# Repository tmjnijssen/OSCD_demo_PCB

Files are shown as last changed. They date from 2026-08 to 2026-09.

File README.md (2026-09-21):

# OSCD Demo PCB


A demonstration / teaching PCB built by the [Open Science Community Delft](https://www.tudelft.nl/en/library/open-science-community-delft) to show what an open hardware project looks like in practice: full sources, an open licence, and everything needed to have the board made and reprogrammed by anyone.

It is a round, ~93 mm ESP32-C3 board shaped like the OSCD logo, with a ring of 12 addressable RGB LEDs, three sensors on a shared I²C bus, capacitive touch pads, and three push buttons. Plug it into USB-C, and the demo firmware lights the ring in response to tilt, touch, ambient light, and button presses.

| | |
|---|---|
| **Revision** | 1.0 |
| **Designer** | Dr. ir. Tim M. J. Nijssen, Open Science Community Delft |
| **Licence** | [CERN-OHL-P v2](LICENSE) (permissive) |
| **EDA tool** | KiCad (2026-era release — see [Opening the design](#opening-the-design)) |

---

## Features

| Block | Part | Interface |
|---|---|---|
| Microcontroller | ESP32-C3-MINI-1 (RISC-V, Wi-Fi + BLE, native USB) | — |
| RGB LEDs | 12 × WS2812B-2020, in a 63 mm ring | 1-wire, `GPIO8` |
| IMU | LSM6DS3 — 3-axis accelerometer + gyroscope | I²C `0x6A` |
| Ambient light | APDS-9306-065 | I²C `0x52` |
| Capacitive touch | MPR121 — 12 electrodes (6 buttons + 6-pad slider) | I²C `0x5A`, IRQ on `GPIO10` |
| Buttons | 3 × user push button, plus RESET and BOOT | `GPIO0/1/2` |
| Power | USB-C 5 V → HT7533-1 LDO → 3.3 V | — |
| Breakout | 2 × 2×5 pin header (5 V, 3.3 V, GND, 9 GPIO) | 2.54 mm |
| Test points | 5 V, 3.3 V, SDA, SCL (each via 100 Ω) | — |

There is no USB-UART bridge — the ESP32-C3's native USB peripheral is wired straight to the USB-C connector, protected by a USBLC6-2SC6 ESD array.

## Quick start

1. **Power it.** Connect a USB-C cable to `J1`. The board is bus-powered; no battery or jumper setting is needed.
2. **Install the toolchain.** Arduino IDE with the *esp32* board package by Espressif, board **ESP32C3 Dev Module**, and **Tools → USB CDC On Boot: Enabled**.
3. **Flash the demo.** Open [`firmware_examples/test_sensors/test_sensors.ino`](firmware_examples/test_sensors/test_sensors.ino) and upload it. Because there is no auto-reset circuit you must enter the bootloader by hand: **hold BOOT (SW2), tap RESET (SW1), release BOOT**, then click Upload. Tap RESET again when the upload finishes.
4. **Watch it.** The ring plays a rainbow sweep at boot, then reacts to tilt, touch, and the three buttons. Open the Serial Monitor at 115200 baud for sensor readings.

Full setup notes, required libraries, and troubleshooting are in [`firmware_examples/README.md`](firmware_examples/README.md).

## Pinout

| ESP32-C3 pin | Function on this board | Also on |
|---|---|---|
| `GPIO0` | Button **SW4** (active low, RC-debounced) | `J2.6` |
| `GPIO1` | Button **SW3** (active low, RC-debounced) | `J2.7` |
| `GPIO2` | Button **SW5** (active low, RC-debounced) | `J2.3` |
| `GPIO3` | APDS-9306 interrupt | `J2.4` |
| `GPIO4` | LSM6DS3 `INT1` | `J2.9` |
| `GPIO5` | LSM6DS3 `INT2` | `J3.3` |
| `GPIO6` | **I²C SCL** (4.7 kΩ pull-up) | `J3.4`, `TP5` |
| `GPIO7` | **I²C SDA** (4.7 kΩ pull-up) | `J3.5`, `TP6` |
| `GPIO8` | WS2812B data out → `D1` | `J3.6` |
| `GPIO9` | BOOT button **SW2** (strapping pin) | `J3.7` |
| `GPIO10` | MPR121 `IRQ` | `J2.8` |
| `GPIO18/19` | USB D− / D+ | — |
| `GPIO20/21` | UART0 RX / TX | `J3.8`, `J3.9` |
| `EN` | RESET button **SW1** | `J2.5` |

**Header pinouts** (2×5, 2.54 mm, odd/even numbering):

```
J2:  1 +5V    2 +3V3    3 GPIO2   4 GPIO3   5 EN
     6 GPIO0  7 GPIO1   8 GPIO10  9 GPIO4  10 GND

J3:  1 +5V    2 +3V3    3 GPIO5   4 GPIO6   5 GPIO7
     6 GPIO8  7 GPIO9   8 GPIO20  9 GPIO21 10 GND
```

**LED ring order:** `D1` sits at the 9 o'clock position and the chain `D1 → D2 → … → D12` runs clockwise, 30° apart.

**Touch electrodes:** `TP2` is the inner 6-pad slider on `ELE0…ELE5`; `TP1` is the outer ring of 6 buttons on `ELE6…ELE11`.

## Repository layout

```
OSCD_demo_PCB.kicad_pro     KiCad project
OSCD_demo_PCB.kicad_sch     Schematic (single sheet)
OSCD_demo_PCB.kicad_pcb     Board layout (4 layers)
schematic.pdf               Rendered schematic, for reading without KiCad
assets/
  OSCD_demo_PCB_symbols.kicad_sym    Project-local symbols
  OSCD_demo_PCB_footprints.pretty/   Project-local footprints (ESP32 module,
                                     touch pads, WS2812B-2020, logo, switches)
  graphics/                          OSCD logo artwork (DXF)
bom/ibom.html               Interactive HTML BOM for hand assembly
production/                 Fabrication outputs (gerbers, drill, BOM, CPL)
firmware_examples/          Arduino sketches
docs/                       Hardware and manufacturing documentation
```

## Opening the design

The sources were saved by a 2026-era KiCad release (schematic file format `20260306`, board format `20260206`). Open them with that release or newer; older KiCad versions will refuse the files.

Symbol and footprint libraries are project-local and resolved through `${KIPRJMOD}` in `sym-lib-table` / `fp-lib-table`, so cloning the repository and opening `OSCD_demo_PCB.kicad_pro` is enough — nothing has to be installed into your global libraries.

## Documentation

- **[docs/hardware.md](docs/hardware.md)** — how each subsystem works, jumper/configuration options, and design notes.
- **[docs/manufacturing.md](docs/manufacturing.md)** — board specification, ordering, and how to regenerate the fabrication files.
- **[firmware_examples/README.md](firmware_examples/README.md)** — toolchain setup, upload procedure, and what the demo does.

## Licence

Hardware and firmware are released under the **CERN Open Hardware Licence Version 2 – Permissive** ([`LICENSE`](LICENSE)). You may use, study, modify, manufacture and sell boards based on this design, including in closed-source products, provided you keep the copyright and licence notices and do not imply endorsement.

The OSCD logo and name are project branding; please replace them with your own if you distribute modified boards.

## Credits

Designed by Dr. ir. Tim M. J. Nijssen for the Open Science Community Delft.

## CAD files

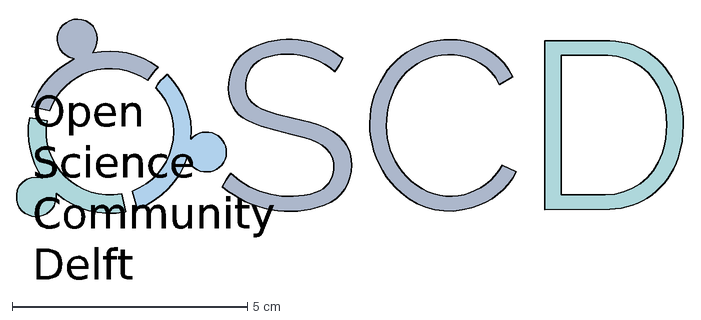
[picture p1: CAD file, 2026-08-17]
assets/graphics/OSCD-logo-fullname.dxf
Open Science Community Delft

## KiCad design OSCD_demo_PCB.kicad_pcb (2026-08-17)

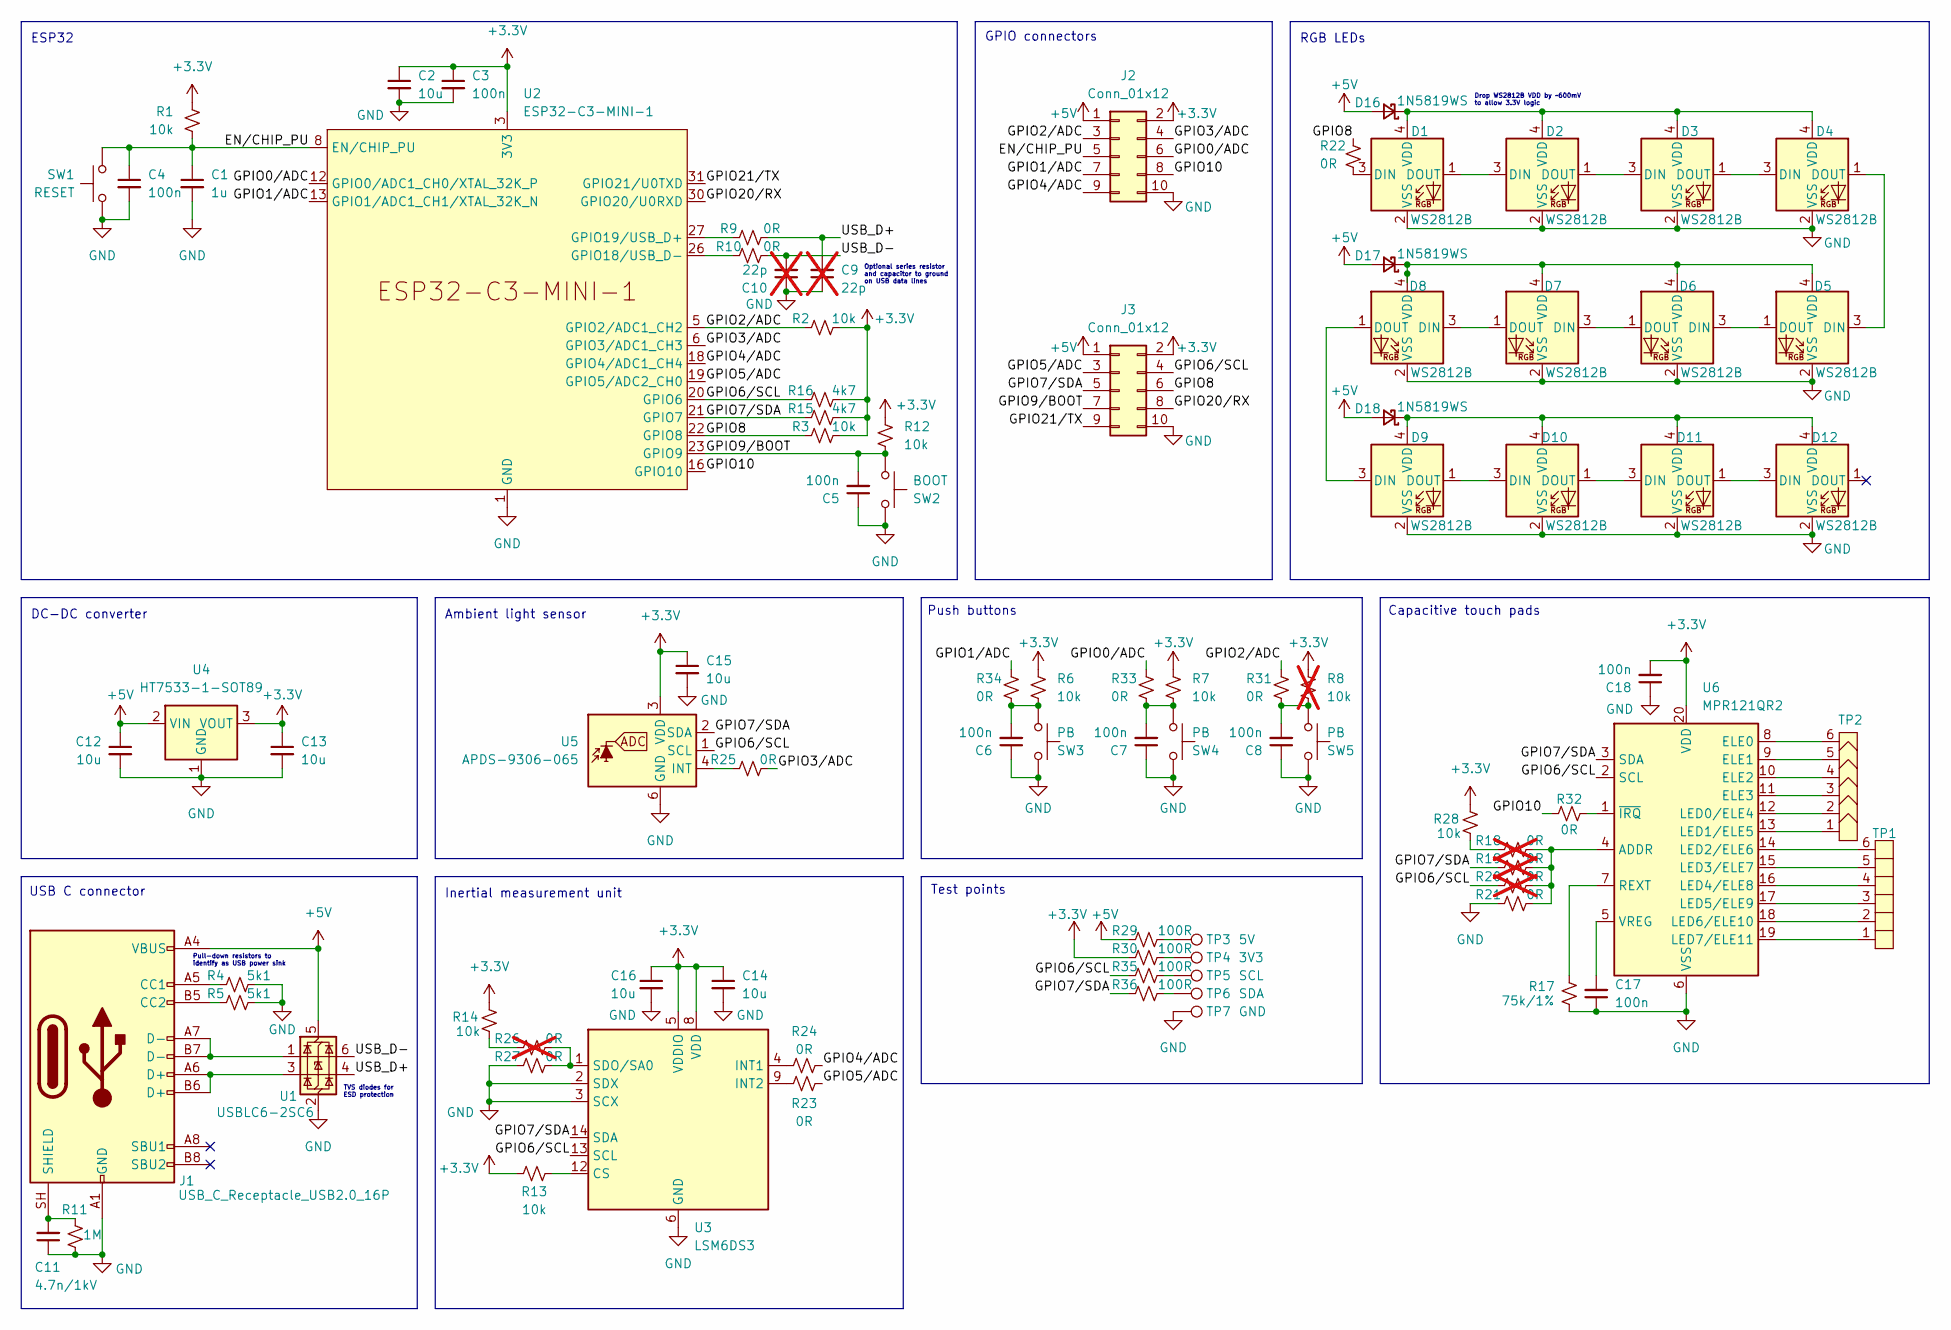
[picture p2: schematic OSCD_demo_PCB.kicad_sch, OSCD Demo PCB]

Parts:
C1: 1u; C_0805_2012Metric_Pad1.18x1.45mm_HandSolder; LCSC C28323
C2, C12, C13, C14, C15, C16: 10u; C_0805_2012Metric_Pad1.18x1.45mm_HandSolder; LCSC C15850
C3, C4, C5, C6, C7, C8, C17, C18: 100n; C_0805_2012Metric_Pad1.18x1.45mm_HandSolder; LCSC C49678
C9, C10: 22p; C_0805_2012Metric_Pad1.18x1.45mm_HandSolder; not fitted
C11: 4.7n/1kV; C_0805_2012Metric_Pad1.18x1.45mm_HandSolder; LCSC C565695
D1, D2, D3, D4, D5, D6, D7, D8, D9, D10, D11, D12: WS2812B; LED_WS2812B-2020_PLCC4_2.0x2.0mm; LCSC C2976072
D16, D17, D18: 1N5819WS; D_SOD-323; LCSC C191023
J1: USB_C_Receptacle_USB2.0_16P; USB_C_Receptacle_GCT_USB4105-xx-A_16P_TopMnt_Horizontal; LCSC C393939
J2, J3: Conn_01x12; PinHeader_2x05_P2.54mm_Vertical
R1, R2, R3, R6, R7, R12, R13, R14, R28: 10k; R_0805_2012Metric_Pad1.20x1.40mm_HandSolder; LCSC C17414
R4, R5: 5k1; R_0805_2012Metric_Pad1.20x1.40mm_HandSolder; LCSC C27834
R8: 10k; R_0805_2012Metric_Pad1.20x1.40mm_HandSolder; not fitted
R9, R10, R21, R22, R23, R24, R25, R27, R31, R32, R33, R34: 0R; R_0805_2012Metric_Pad1.20x1.40mm_HandSolder; LCSC C17477
R11: 1M; R_0805_2012Metric_Pad1.20x1.40mm_HandSolder; LCSC C17514
R15, R16: 4k7; R_0805_2012Metric_Pad1.20x1.40mm_HandSolder; LCSC C17673
R17: 75k/1%; R_0805_2012Metric_Pad1.20x1.40mm_HandSolder; LCSC C17819
R18, R19, R20, R26: 0R; R_0805_2012Metric_Pad1.20x1.40mm_HandSolder; not fitted
R29, R30, R35, R36: 100R; R_0805_2012Metric_Pad1.20x1.40mm_HandSolder; LCSC C17408
SW1: RESET; SMD_SW_1P1T_TS-1088-AR02016; LCSC C720477
SW2: BOOT; SMD_SW_1P1T_TS-1088-AR02016; LCSC C720477
SW3, SW4, SW5: PB; SW_SPST_PTS645Sx43SMTR92; LCSC C2837531
TP1: 6_pad_touch_slider; 6_pad_touch_buttons
TP2: 6_pad_touch_slider
TP3: 5V; TestPoint_Pad_D2.0mm
TP4: 3V3; TestPoint_Pad_D2.0mm
TP5: SCL; TestPoint_Pad_D2.0mm
TP6: SDA; TestPoint_Pad_D2.0mm
TP7: GND; TestPoint_Pad_D2.0mm
U1: USBLC6-2SC6; SOT-23-6; LCSC C7519
U2: ESP32-C3-MINI-1; LCSC C2838502
U3: LSM6DS3; LGA-14_3x2.5mm_P0.5mm_LayoutBorder3x4y; LCSC C967633
U4: HT7533-1-SOT89; SOT-89-3; LCSC C14289
U5: APDS-9306-065; Broadcom_DFN-6_2x2mm_P0.65mm; LCSC C2649498
U6: MPR121QR2; UQFN-20_3x3mm_P0.4mm; LCSC C91322

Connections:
+3.3V: C2.1, C3.1, C13.1, C14.1, C15.1, C16.1, C18.2, J2.2, J3.2, R1.1, R2.2, R3.2, R6.2, R7.2, R8.2, R12.1, R13.1, R14.2, R15.2, R16.2, R28.2, R30.1, U2.3 (3V3), U3.5 (VDDIO), U3.8 (VDD), U4.3 (VOUT), U5.3 (VDD), U6.20 (VDD)
+5V: C12.1, D16.2 (A), D17.2 (A), D18.2 (A), J1.A4 (VBUS), J1.A9 (VBUS), J1.B4 (VBUS), J1.B9 (VBUS), J2.1, J3.1, R29.1, U1.5 (VBUS), U4.2 (VIN)
/EN/CHIP_PU: C1.1, C4.1, J2.5, R1.2, SW1.2, U2.8 (EN/CHIP_PU)
/GPIO0/ADC: J2.6, R33.1, U2.12 (GPIO0/ADC1_CH0/XTAL_32K_P)
/GPIO1/ADC: J2.7, R34.1, U2.13 (GPIO1/ADC1_CH1/XTAL_32K_N)
/GPIO2/ADC: J2.3, R2.1, R31.1, U2.5 (GPIO2/ADC1_CH2)
/GPIO3/ADC: J2.4, R25.1, U2.6 (GPIO3/ADC1_CH3)
/GPIO4/ADC: J2.9, R24.1, U2.18 (GPIO4/ADC1_CH4)
/GPIO5/ADC: J3.3, R23.1, U2.19 (GPIO5/ADC2_CH0)
/GPIO6/SCL: J3.4, R16.1, R20.2, R35.1, U2.20 (GPIO6), U3.13 (SCL), U5.1 (SCL), U6.2 (SCL)
/GPIO7/SDA: J3.5, R15.1, R19.2, R36.1, U2.21 (GPIO7), U3.14 (SDA), U5.2 (SDA), U6.3 (SDA)
/GPIO8: J3.6, R3.1, R22.1, U2.22 (GPIO8)
/GPIO9/BOOT: C5.2, J3.7, R12.2, SW2.1, U2.23 (GPIO9)
/GPIO10: J2.8, R32.2, U2.16 (GPIO10)
/GPIO20/RX: J3.8, U2.30 (GPIO20/U0RXD)
/GPIO21/TX: J3.9, U2.31 (GPIO21/U0TXD)
/USB_D+: C9.2, R9.2, U1.4 (I/O2)
/USB_D-: C10.2, R10.2, U1.6 (I/O1)
GND: C1.2, C2.2, C3.2, C4.2, C5.1, C6.1, C7.1, C8.1, C9.1, C10.1, C11.1, C12.2, C13.2, C14.2, C15.2, C16.2, C17.1, C18.1, D1.2 (VSS), D2.2 (VSS), D3.2 (VSS), D4.2 (VSS), D5.2 (VSS), D6.2 (VSS), D7.2 (VSS), D8.2 (VSS), D9.2 (VSS), D10.2 (VSS), D11.2 (VSS), D12.2 (VSS), J1.A1 (GND), J1.A12 (GND), J1.B1 (GND), J1.B12 (GND), J2.10, J3.10, R4.2, R5.2, R11.1, R17.1, R21.2, R27.2, SW1.1, SW2.2, SW3.2, SW4.2, SW5.2, TP7.1 (1_1), U1.2 (GND), U2.1 (GND), U2.2 (GND), U2.11 (GND), U2.14 (GND), U2.36 (GND), U2.37 (GND), U2.38 (GND), U2.39 (GND), U2.40 (GND), U2.41 (GND), U2.42 (GND), U2.43 (GND), U2.44 (GND), U2.45 (GND), U2.46 (GND), U2.47 (GND), U2.48 (GND), U2.49 (GND), U2.50 (GND), U2.51 (GND), U2.52 (GND), U2.53 (GND), U3.2 (SDX), U3.3 (SCX), U3.6 (GND), U3.7 (GND), U4.1 (GND), U5.6 (GND), U6.6 (VSS)
unnamed: C6.2, R6.1, R34.2, SW3.1
unnamed: C7.2, R7.1, R33.2, SW4.1
unnamed: C8.2, R8.1, R31.2, SW5.1
unnamed: D1.3 (DIN), R22.2
unnamed: D1.1 (DOUT), D2.3 (DIN)
unnamed: D1.4 (VDD), D2.4 (VDD), D3.4 (VDD), D4.4 (VDD), D16.1 (K)
unnamed: D2.1 (DOUT), D3.3 (DIN)
unnamed: D3.1 (DOUT), D4.3 (DIN)
unnamed: D4.1 (DOUT), D5.3 (DIN)
unnamed: D5.1 (DOUT), D6.3 (DIN)
unnamed: D6.1 (DOUT), D7.3 (DIN)
unnamed: D7.1 (DOUT), D8.3 (DIN)
unnamed: D8.1 (DOUT), D9.3 (DIN)
unnamed: D9.1 (DOUT), D10.3 (DIN)
unnamed: D10.1 (DOUT), D11.3 (DIN)
unnamed: D9.4 (VDD), D10.4 (VDD), D11.4 (VDD), D12.4 (VDD), D18.1 (K)
unnamed: D11.1 (DOUT), D12.3 (DIN)
unnamed: D5.4 (VDD), D6.4 (VDD), D7.4 (VDD), D8.4 (VDD), D17.1 (K)
unnamed: J1.A5 (CC1), R4.1
unnamed: J1.B5 (CC2), R5.1
unnamed: J1.A6 (D+), J1.B6 (D+), U1.3 (I/O2)
unnamed: J1.A7 (D-), J1.B7 (D-), U1.1 (I/O1)
unnamed: C11.2, J1.SH (SHIELD), R11.2
unnamed: R14.1, R26.2
unnamed: R18.2, R28.1
unnamed: R29.2, TP3.1 (1_1)
unnamed: R30.2, TP4.1 (1_1)
unnamed: R35.2, TP5.1 (1_1)
unnamed: R36.2, TP6.1 (1_1)
unnamed: R10.1, U2.26 (GPIO18/USB_D-)
unnamed: R9.1, U2.27 (GPIO19/USB_D+)
unnamed: R13.2, U3.12 (CS)
unnamed: R24.2, U3.4 (INT1)
unnamed: R23.2, U3.9 (INT2)
unnamed: R26.1, R27.1, U3.1 (SDO/SA0)
unnamed: R25.2, U5.4 (INT)
unnamed: R18.1, R19.1, R20.1, R21.1, U6.4 (ADDR)
unnamed: TP2.6 (Pad_6), U6.8 (ELE0)
unnamed: TP2.5 (Pad_5), U6.9 (ELE1)
unnamed: TP2.4 (Pad_4), U6.10 (ELE2)
unnamed: TP2.3 (Pad_3), U6.11 (ELE3)
unnamed: TP2.2 (Pad_2), U6.12 (LED0/ELE4)
unnamed: TP2.1 (Pad_1), U6.13 (LED1/ELE5)
unnamed: TP1.6 (Pad_6), U6.14 (LED2/ELE6)
unnamed: TP1.5 (Pad_5), U6.15 (LED3/ELE7)
unnamed: TP1.4 (Pad_4), U6.16 (LED4/ELE8)
unnamed: TP1.3 (Pad_3), U6.17 (LED5/ELE9)
unnamed: TP1.2 (Pad_2), U6.18 (LED6/ELE10)
unnamed: TP1.1 (Pad_1), U6.19 (LED7/ELE11)
unnamed: R17.2, U6.7 (REXT)
unnamed: C17.2, U6.5 (VREG)
unnamed: R32.1, U6.1 (~IRQ)

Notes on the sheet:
DC-DC converter
Ambient light sensor
Push buttons
Optional series resistor and capacitor to ground on USB data lines
Inertial measurement unit
GPIO connectors
USB C connector
RGB LEDs
Test points
TVS diodes for ESD protection
ESP32
Drop WS2812B VDD by ~600mV to allow 3.3V logic
Capacitive touch pads
Pull-down resistors to identify as USB power sink

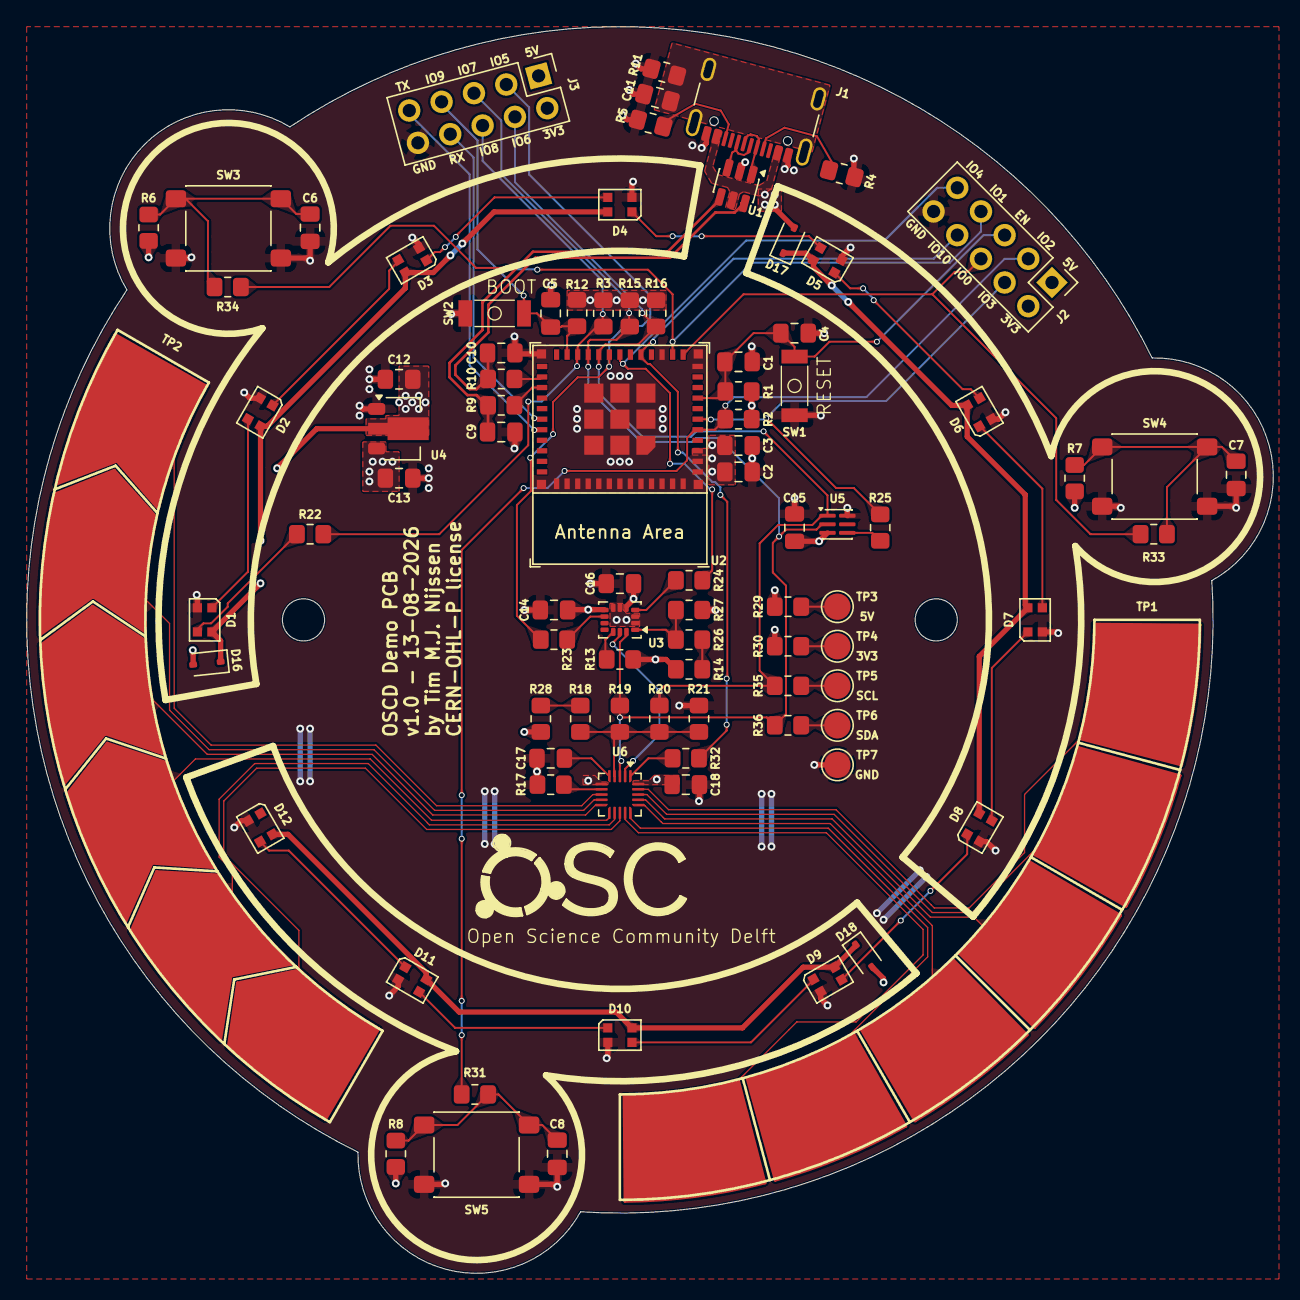
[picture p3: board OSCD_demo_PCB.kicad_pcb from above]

Board: 4 copper layers, 94.6 x 94.6 mm, 90 parts (0 on the bottom side), 71 nets.

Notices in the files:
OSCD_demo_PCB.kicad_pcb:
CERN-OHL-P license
